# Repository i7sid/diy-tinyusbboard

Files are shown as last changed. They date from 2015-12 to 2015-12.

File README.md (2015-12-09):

# diy-tinyusbboard
Das DIY tinyUSBboard ist abgeleitet vom [tinyusbboard](https://github.com/tinyusbboard) und wurde für die Vorlesung ["DIY: Personal Fabrication"](http://www7.cs.fau.de/de/teaching/diy-2015w/) als Löttutorial entwickelt.

## In der Arduino IDE
Ab der Arduino IDE 1.6.4 kann man dieses Board mit der [Boards Manager URL](https://github.com/i7sid/diy-tinyusbboard/raw/master/Arduino/package_diy-tinyusbboard_index.json) hinzufügen.

Board Manager Link: `https://github.com/i7sid/diy-tinyusbboard/raw/master/Arduino/package_diy-tinyusbboard_index.json`

Zum Ätzen, Löten und ersten Programmieren besteht eine [Anleitung](https://github.com/i7sid/diy-tinyusbboard/raw/master/anleitung/anleitung.pdf).
### Arduino PIN-Belegung
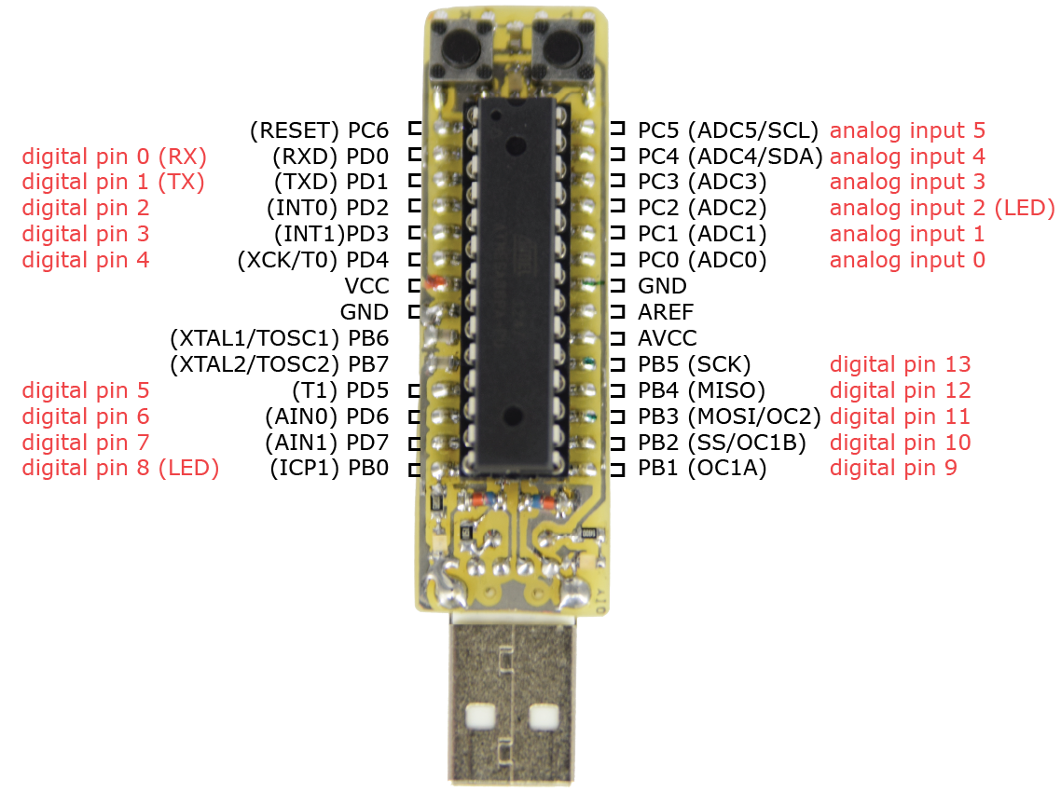
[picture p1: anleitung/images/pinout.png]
DIY tinyUSBboard Arduino PIN names


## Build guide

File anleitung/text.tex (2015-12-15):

\title{DIY tinyUSBboard}
\subtitle{Lötanleitung}
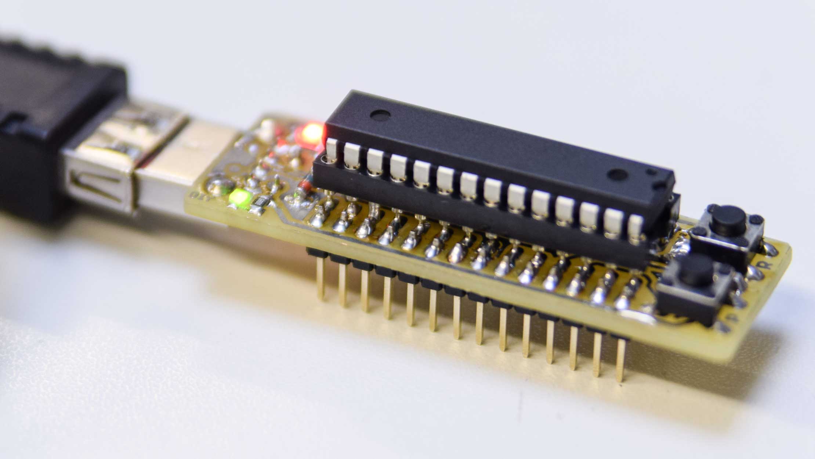
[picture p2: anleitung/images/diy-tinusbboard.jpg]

\section{Ätzen}
Zuerst muss das Layout auf die Platine geätzt werden.
Das Dokument spiegeln und mit möglichst hoher Tonerdichte ausgedrucken. Wenn nötig Photoplatine auf passende Größe zurecht sägen und Grate mit einer kleinen Feile entfernen. 
\paragraph*{Belichten} Die blaue Schutzfolie entfernen und auf dem gedruckten Layout im Belichter platzieren. Dabei muss die bedruckte Seite auf der beschichteten Seite der Platine aufliegen. Belichter schließen und mit empfohlene Belichtungszeit für den Belichter belichten. 
\paragraph*{Entwickeln} Mit aufgesetzter Schutzbrille die Platine, mit der beschichteten Seite nach oben, in die dafür vorgesehene Schale legen und mit etwas NaOH-Lösung begießen.
20-30 Sekunden schwenken bis keine braune Färbung mehr in die Lösung übergeht.
Platine mit einer Plastikpinzette aus der Lösung entnehmen und unter fliesendem Wasser abspülen.
\paragraph*{Ätzen} Warten bis das Ätzbad 40$^\circ$C erreicht hat. Ätzgerät ausschalten mit aufgesetzer Schutzbrille den Platinenhalter entnehmen, die Platine in den Halter einlegen. Halter in das Ätzbad stellen und Gerät wieder einschalten.
Ätzvorgang regelmäßig beobachten. Sobald alle gewünschten Stellen frei von Kupfer sind, Schutzbrille aufsetzen, Atzgerät ausschalten, Platinenhalter mit Platine entnehmen und mit Wasser abspülen.

\paragraph*{Entschichten} Platine erneut (ohne Papier ca. 2 Minuten) belichten und in die NaOH-Lösung geben. Schwenken, bis sich keine braune Farbe mehr löst.
Schale ins Waschbecken leeren und zusammen mit der Platine abspülen.
Platine im Verzinnungsbad verzinnen und erneut unter fließendem Wasser abwaschen.
\section{Bohren}
Beim Präzisionssockel kann man sich Zeit und abgebrochene Bohrer sparen, indem man nur die vier Ecken bohrt
\img{bohren.pdf}{Durchmesser der zu Bohrenden Löcher}
\section{Bestücken}
\subsection{SMT}
Die SMD Komponenten werden zuerst bestückt.
Dabei erhitzt man erst eines der Pads mit dem Lötkolben und bringt etwas Lötzinn auf. Dann wird das Bauteil mit einer Pinzette in die richtige Position gebracht. Das verzinnte Pad wird erneut erhitzt. Dann wird der andere Kontakt des Bauteils verlötet.
\paragraph*{Z-Dioden} Die Z-Dioden müssen richtig orientiert verlötet werden. Der blaue Ring markiert die Kathode der Diode. 

\img{z-dioden.pdf}{Orientierung und Position der Z-Dioden (blau)}

\paragraph*{Widerstände} Die Bauteilwerte sind auf den Widerständen aufgedruckt.
Dabei sind bei einer dreistelligen Aufschrift die ersten beiden Ziffern mit der Zehnerpotenz der dritten Ziffer zu multiplizieren. Beispiel $103 = 10 \cdot 10^3 = 10\,\mathrm{k}\Omega$\\
Bei vierstelliger Aufschrift werden die ersten drei Ziffern mit der Zehnerpotenz der letzten Ziffer multipliziert. Beispiel $6800 = 680 * 10^0 = 680\,\Omega$\\
Wird keine Zehnerpotenz angegeben wird der Buchstabe R an der Stelle des Kommas eingefügt. Beispiel $68\mathrm{R}0 = 68,0\,\Omega$
\img{widerstaende.pdf}{Position und Werte der Widerstände}

\paragraph*{Kondensatoren}
Die Kondensatoren lassen sich duch ihre Verpackung unterscheiden. Der einzige in Kunststoffhülle hat die Kapazität $1\,\mu \mathrm{F}$. Der zweier Abschnitt hat den Wert $18\,\mathrm{pF}$ und der übrige den Wert $100\, \mathrm{nF}$
\img{kondensatoren.pdf}{Position und Werte der Kondensatoren}
\paragraph*{LEDs}
Auf dem tinyUSBboard kommen eine grüne und zwei rote LEDs zum Einsatz.
\img{led-farbe.pdf}{Farben der LEDs}
\newpage
Die Kathode einer LED ist rückseitig, wie auf dem Schaltplan, mit einem Quadrat markiert.
\img{led-orientierung.pdf}{Markierung der Kathode im Bestückungsdruck und auf der \textbf{Rückseite} der LED}

\subsection{THT}
Nachdem alle SMD Komponenten verlötet sind werden die beiden Taster auf der Kupferseite verbaut.
Danach Oszillator, PTC-Widerstand und USB-Buchse; diese drei Komponenten werden von der Rückseite der Platine bestückt und auf der Kupferseite verlötet.
\img{tht.pdf}{Position THT Komponenten}

Erst wenn alle andere Komponenten mit Ausnahme der Stiftleisten verlötet sind wird der Sockel eingesetzt. Wenn nur die Löcher in den 4 Ecken gebohrt wurden müssen vor dem Löten die übrigen Pins gleichmäßig gekürzt werden. Der Sockel besitzt auf einer der Stirnseiten eine Kerbe, diese dient zur späteren Orientierung des ATmega88-PA und sollte zu den Tastern zeigen.
Nachdem der Sockel verbaut ist werden zuletzt die Stiftleisten von der Unterseite bestückt und auf der Kupferseite verlötet.\\
Jetzt kann der ATmega88PA in das Board eingesetzt werden. In einer Ecke ist ein Punkt für Pin 1 (Reset) eingeprägt, dieser muss zu den Tastern zeigen.

\section{tinyUSBboard in Arduino IDE}
Um das DIY tinyUSBboard in der Arduino IDE verwenden zu können ist eine aktuelle Arduino IDE vorausgesetzt. In der Arduino IDE die Einstellungen öffnen \enquote{File $\rightarrow$ Preferences} und in das Feld \enquote{Additional Boards Manager URLs} die URL \url{https://github.com/i7sid/diy-tinyusbboard/raw/master/Arduino/package_diy-tinyusbboard_index.json} kopieren. Unter \enquote{Tools $\rightarrow$ Board $\rightarrow$ Boards Manager} den Boards Manager aufrufen, den Eintrag diy-tinyusbboard auswählen und \enquote{Install} klicken. Jetzt kann das diy-tinyusbboard ausgewählt werden \enquote{Tools $\rightarrow$ Board $\rightarrow$ DIY tinyUSBboard (USBaspLoader ATmega88p at 16MHz)}.\footnote{Für Windows muss zusätzlich ein Treiber für USBasp installiert werden. \url{http://www.fischl.de/usbasp/}}
\image{boards-manager.png}{tinyUSBboard im Boards Manager}
\subsection{Bootloader flashen}
Zum flashen des Bootloaders muss das tinyUSBboard an einen AVR ISP\footnote{z.B. Atmel AVRISP mkII oder USBasp} angeschlossen werden. Je nach ISP muss das Board noch z.B. über die USB-Buchse mit Spannung versorgt werden.
\img{prog.pdf}{ISP an das tinyUSBboard anschließen}

Wenn in der Arduino IDE das richtige Board ausgewählt ist muss noch der verwendete ISP eingestellt werden \enquote{Tools $\rightarrow$ Programmer}. Jetzt kann mit \enquote{Tools $\rightarrow$ Burn Bootloader} der Bootloader auf das DIY tinyUSBboard geflasht werden.

\subsection{Sketch auf das Board flashen}
Um das tinyUSBboard in den Programmiermodus zu bringen muss der \textbf{P}-Taster gedrückt werden, während der \textbf{R}-Taster losgelassen wird. Das tinyUSBboard meldet sich jetzt als USBasp ISP am Computer an und lässt sich in der Arduino IDE mit \enquote{Sketch $\rightarrow$ Upload} programmieren. Wenn die Arduino IDE \enquote{Done uploading.} angezeigt wird, kann der Programmablauf durch Drücken einer der Tasten gestartet werden. 
\image{pinout.pdf}{Arduino PIN-Namen}

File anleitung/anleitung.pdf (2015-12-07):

## DIY tinyUSBboard


## 1 Atzen ¨

Zuerst muss das Layout auf die Platine geätzt werden. Das Dokument spiegeln und mit möglichst hoher Tonerdichte ausgedrucken. Wenn nötig Photoplatine auf passende Größe zurecht sägen und Grate mit einer kleinen Feile entfernen.

Belichten Die blaue Schutzfolie entfernen und auf dem gedruckten Layout im Belichter platzieren. Dabei muss die bedruckte Seite auf der beschichteten Seite der Platine aufliegen. Belichter schließen und mit empfohlene Belichtungszeit fur den Belichter belichten. ¨

Entwickeln Mit aufgesetzter Schutzbrille die Platine, mit der beschichteten Seite nach oben, in die dafur ¨ vorgesehene Schale legen und mit etwas NaOH-Lösung begießen. 20-30 Sekunden schwenken bis keine
braune Färbung mehr in die Lösung ubergeht. Platine mit einer Plastikpinzette aus der L ¨ | ösung entnehmen
und unter fliesendem Wasser abspulen. ¨
Atzen ¨ | Warten bis das Atzbad 40 ¨ | ◦C erreicht hat. Atzger ¨ | ät ausschalten mit aufgesetzer Schutzbrille den
Platinenhalter entnehmen, die Platine in den Halter einlegen. Halter in das Atzbad stellen und Ger ¨ | ät
wieder einschalten. Atzvorgang regelm ¨ | äßig beobachten. Sobald alle gewunschten Stellen frei von Kupfer ¨

sind, Schutzbrille aufsetzen, Atzgerät ausschalten, Platinenhalter mit Platine entnehmen und mit Wasser abspulen. ¨

kontakt@fablab.fau.de | 7. Dezember 2015

Entschichten Platine erneut (ohne Papier ca. 2 Minuten) belichten und in die NaOH-Lösung geben.

Schwenken, bis sich keine braune Farbe mehr löst. Schale ins Waschbecken leeren und zusammen mit der Platine abspulen. Platine im Verzinnungsbad verzinnen und erneut unter fließendem Wasser abwaschen. ¨

## 2 Bohren

Beim Präzisionssockel kann man sich Zeit und abgebrochene Bohrer sparen, indem man nur die vier Ecken
0.8 mm
0.9 mm

1.2 mm

1.0 mm

2.2 mm

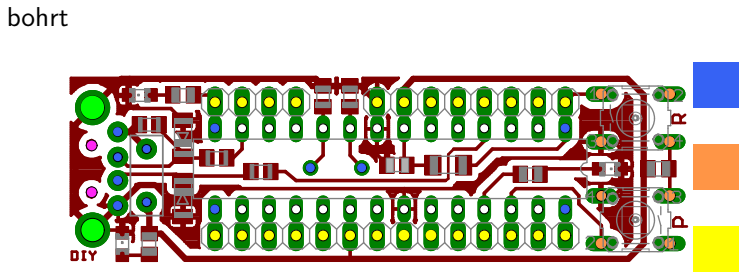
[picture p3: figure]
bohrt

Abbildung 1: Durchmesser der zu Bohrenden Löcher

## 3 Bestücken

### 3.1 SMT

Die SMD Komponenten werden zuerst bestuckt. Dabei erhitzt man erst eines der Pads mit dem L ¨ | ötkolben
und bringt etwas Lötzinn auf. Dann wird das Bauteil mit einer Pinzette in die richtige Position gebracht. Das verzinnte Pad wird erneut erhitzt. Dann wird der andere Kontakt des Bauteils verlötet.
Z-Dioden Die Z-Dioden mussen richtig orientiert verl ¨ | ötet werden. Der blaue Ring markiert die Kathode
der Diode.

Abbildung 2: Orientierung und Position der Z-Dioden (blau)

Widerstände Die Bauteilwerte sind auf den Widerständen aufgedruckt. Dabei sind bei einer dreistelligen Aufschrift die ersten beiden Ziffern mit der Zehnerpotenz der dritten Ziffer zu multiplizieren. Beispiel 103 = 10 · 10³ = 10 kΩ

Bei vierstelliger Aufschrift werden die ersten drei Ziffern mit der Zehnerpotenz der letzten Ziffer multipliziert.

Beispiel 6800 = 680 ∗ 10⁰ = 680 Ω

Wird keine Zehnerpotenz angegeben wird der Buchstabe R an der Stelle des Kommas eingefugt. Beispiel ¨

10k | (103)
68 | (68R0)

1.5k (1501)

680 (6800)

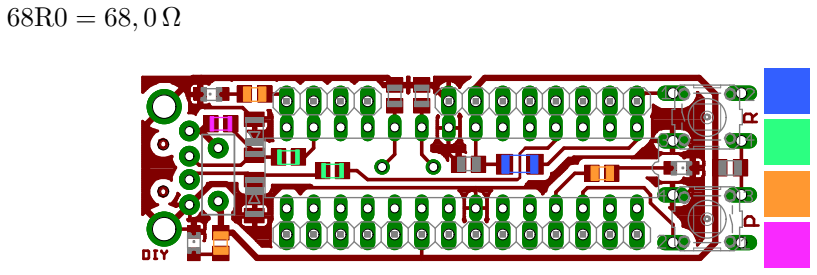
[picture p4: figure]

Abbildung 3: Position und Werte der Widerstände

Kondensatoren Die Kondensatoren lassen sich duch ihre Verpackung unterscheiden. Der einzige in
Kunststoffhulle hat die Kapazit ¨ | ät 1 µF. Der zweier Abschnitt hat den Wert 18 pF und der ubrige den Wert ¨
100 nF
1µF
100 nF
18pF

Abbildung 4: Position und Werte der Kondensatoren

LEDs Auf dem tinyUSBboard kommen eine grune und zwei rote LEDs zum Einsatz. ¨

Abbildung 5: Farben der LEDs

Die Kathode einer LED ist ruckseitig, wie auf dem Schaltplan, mit einem Quadrat markiert. ¨

# Kathode

# Anode

Abbildung 6: Markierung der Kathode

### 3.2 THT

Nachdem alle SMD Komponenten verlötet sind werden die beiden Taster auf der Kupferseite verbaut. Danach Oszillator, PTC-Widerstand und USB-Buchse; diese drei Komponenten werden von der Ruckseite ¨
der Platine bestuckt und auf der Kupferseite verl ¨ | ötet.

# OSC Taster

# PTC

# USB

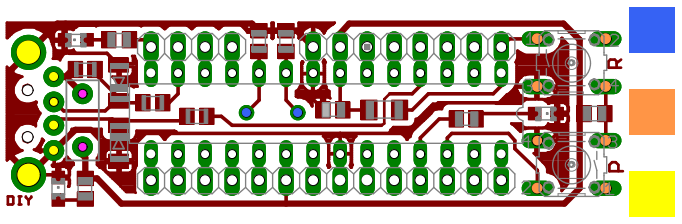
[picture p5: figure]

Abbildung 7: Position THT Komponenten

Erst wenn alle andere Komponenten mit Ausnahme der Stiftleisten verlötet sind wird der Sockel eingesetzt.
Wenn nur die Löcher in den 4 Ecken gebohrt wurden mussen vor dem L ¨ | öten die ubrigen Pins gleichm ¨ | äßig
gekurzt werden. Nachdem der Sockel verbaut ist werden zuletzt die Stiftleisten von der Unterseite best ¨ | | uckt ¨
und auf der Kupferseite verlötet.

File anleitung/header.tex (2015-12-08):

\newcommand{\basedir}{fablab-document}
\documentclass{\basedir/fablab-document}

% \usepackage{fancybox} %ovale Boxen für Knöpfe - nicht mehr benötigt
\usepackage{amssymb} % Symbole für Knöpfe
\usepackage{subfigure,caption}
\usepackage{eurosym}
\usepackage{tabularx} % Tabellen mit bestimmtem Breitenverhältnis der Spalten
\usepackage{wrapfig} % Textumlauf um Bilder

\renewcommand{\texteuro}{\euro}

\definecolor{dunkelgruen}{rgb}{0,0.4,0}

\newcommand{\img}[2]{
	\begin{figure}[ht]
	\centering
	
	\caption{#2}
	\end{figure}}
	
\newcommand{\image}[2]{
	\begin{figure}[ht]
	\centering
	
	\caption{#2}
	\end{figure}}
	
\newcommand\circlearound[1]{%
  \tikz[baseline]\node[draw,shape=circle,anchor=base] {#1} ;}
	
\newcounter{ueberpunkte}
\setcounter{ueberpunkte}{1}
\renewcommand{\labelenumi}{\circlearound{\theueberpunkte}\stepcounter{ueberpunkte}}

\linespread{1.2}

\title{DIY tinyUSBboard}

\begin{document}

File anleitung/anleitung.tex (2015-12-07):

\input{header}
\input{text}
\input{footer}

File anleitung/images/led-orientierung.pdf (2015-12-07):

Kathode

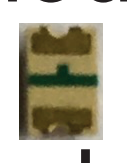
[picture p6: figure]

Anode

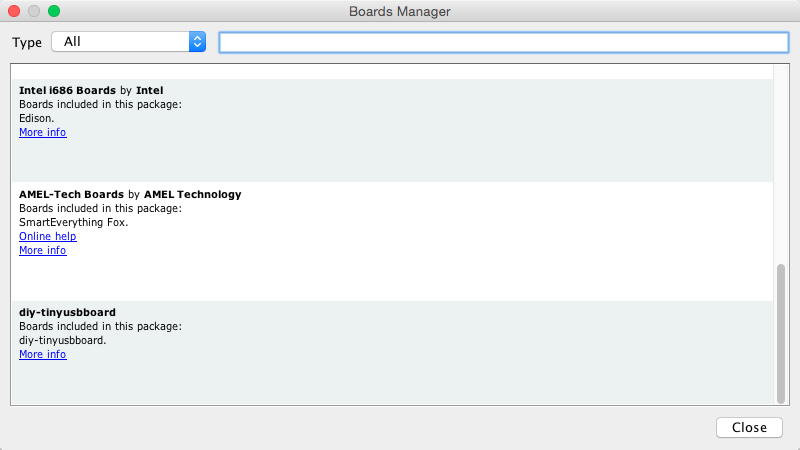
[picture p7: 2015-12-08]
anleitung/images/boards-manager.png

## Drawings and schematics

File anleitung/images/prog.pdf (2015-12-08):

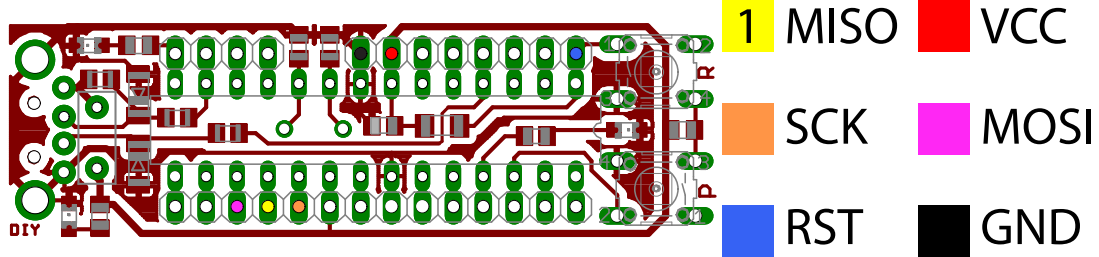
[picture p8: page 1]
RST; SCK; MOSI; MISO; GND; VCC

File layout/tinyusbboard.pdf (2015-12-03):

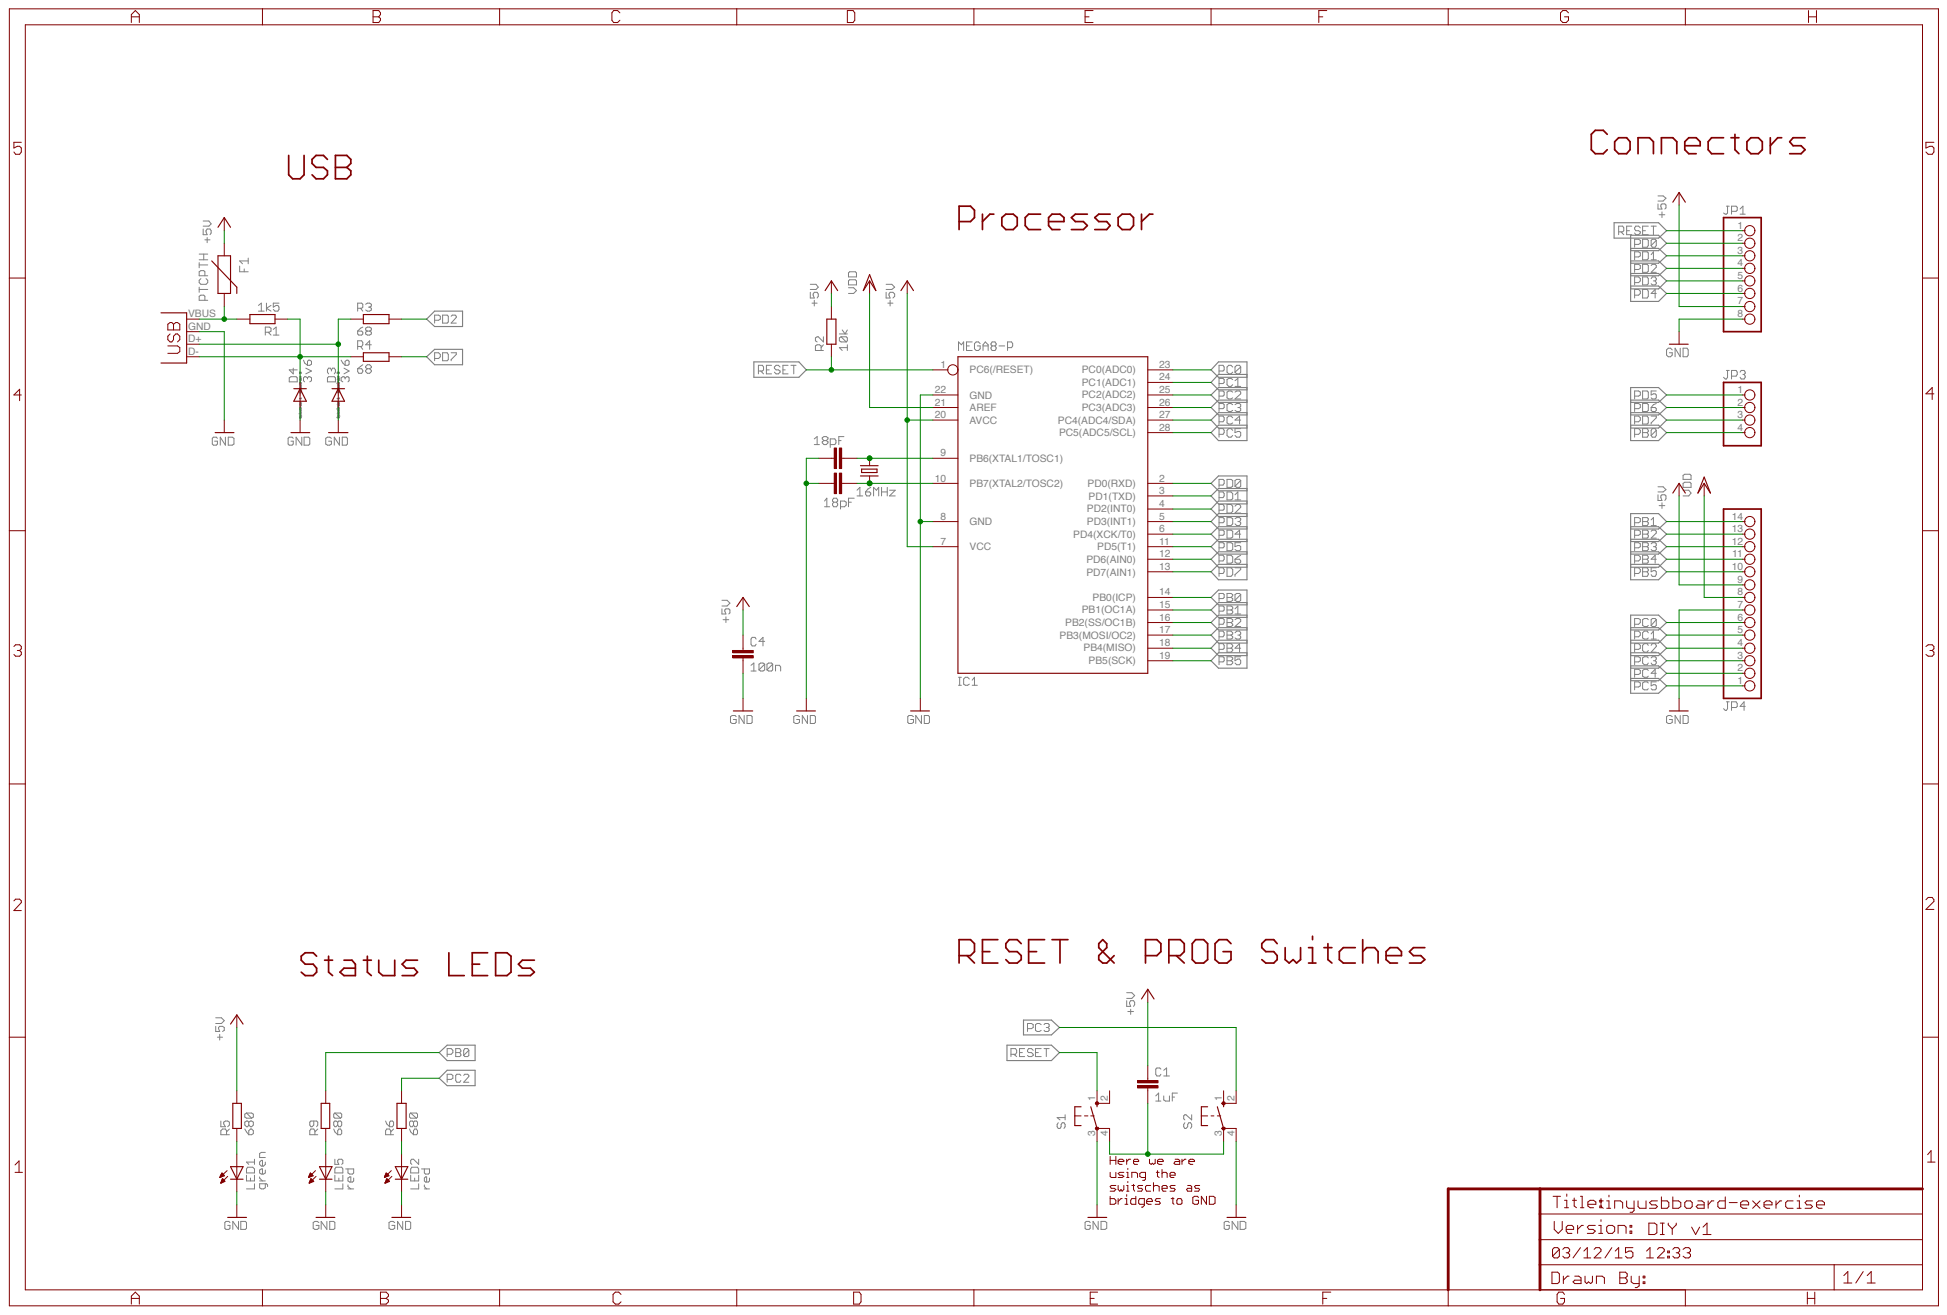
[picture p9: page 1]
PB5(SCK); PB6(XTAL1/TOSC1); GND; VCC; GND 22 AREF 21; PB4(MISO); 18 PB3(MOSI/OC2); 15 PB0(ICP); PD7(AIN1); 13 PD6(AIN0); 11 PD4(XCK/T0); 6 PD3(INT1); 5 PD2(INT0); 4 PD1(TXD); 3 PD0(RXD); PC5(ADC5/SCL); 28 PC4(ADC4/SDA); 27 PC3(ADC3); 26 PC2(ADC2); 25 PC1(ADC1); 24 PC0(ADC0); 23 PC6(/RESET); VBUS

AVCC 20

PB7(XTAL2/TOSC2) 10

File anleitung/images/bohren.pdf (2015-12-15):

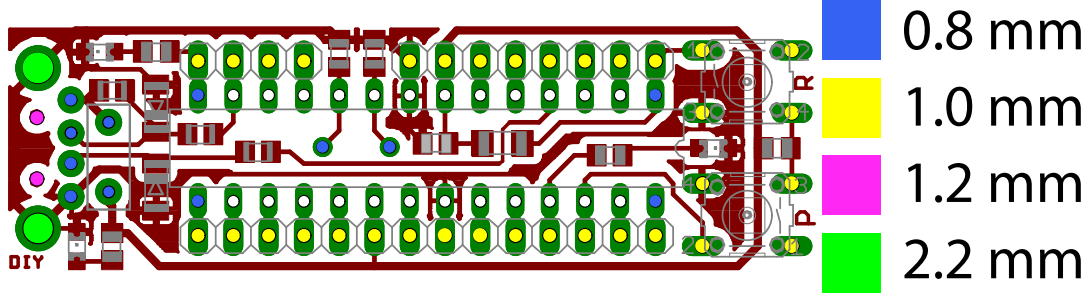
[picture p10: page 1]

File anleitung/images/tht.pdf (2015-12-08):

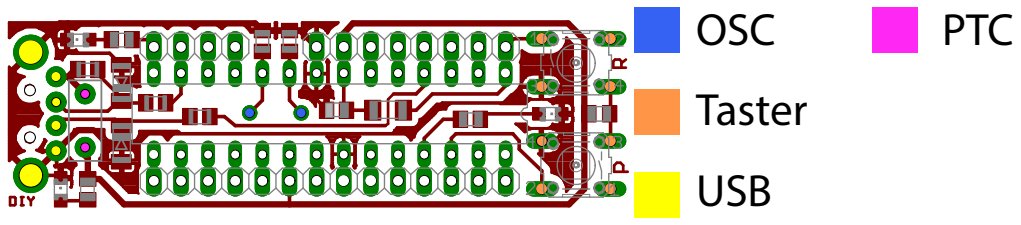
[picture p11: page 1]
OSC Taster; PTC; USB

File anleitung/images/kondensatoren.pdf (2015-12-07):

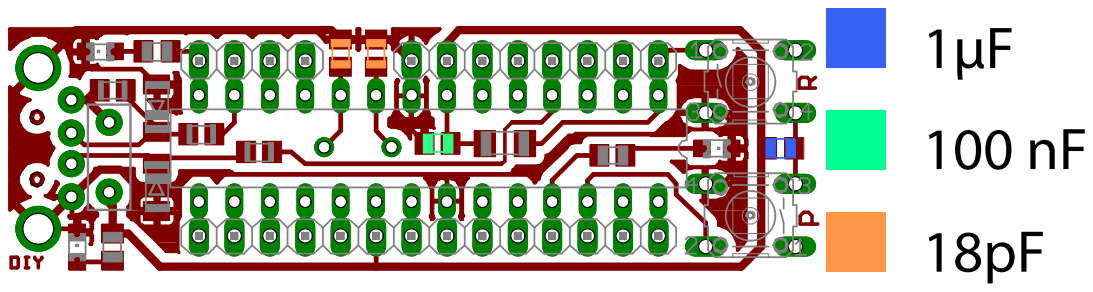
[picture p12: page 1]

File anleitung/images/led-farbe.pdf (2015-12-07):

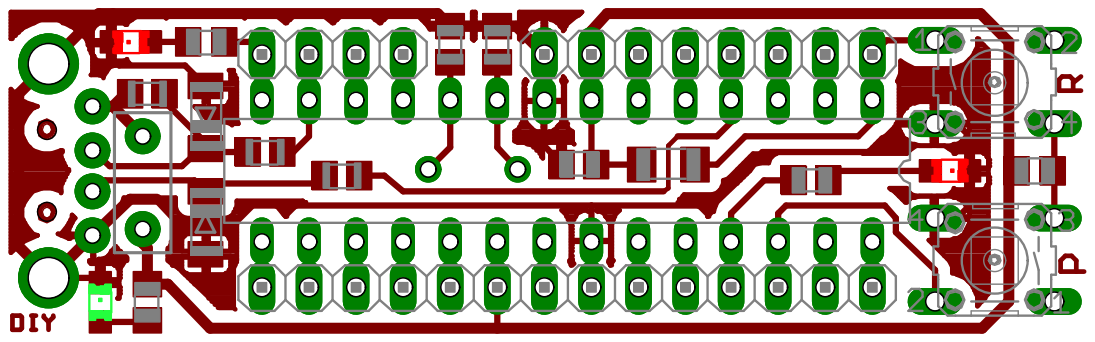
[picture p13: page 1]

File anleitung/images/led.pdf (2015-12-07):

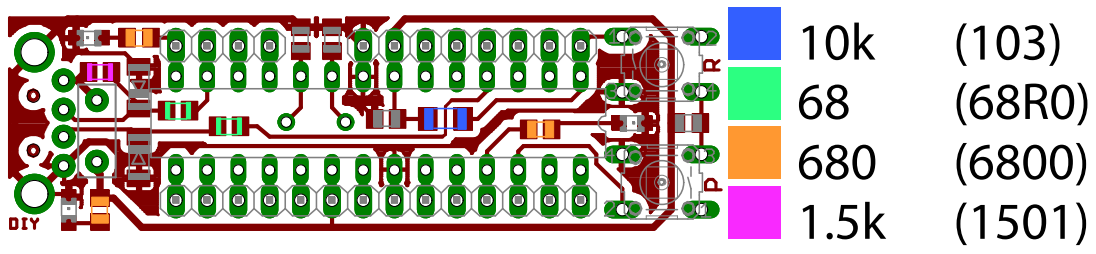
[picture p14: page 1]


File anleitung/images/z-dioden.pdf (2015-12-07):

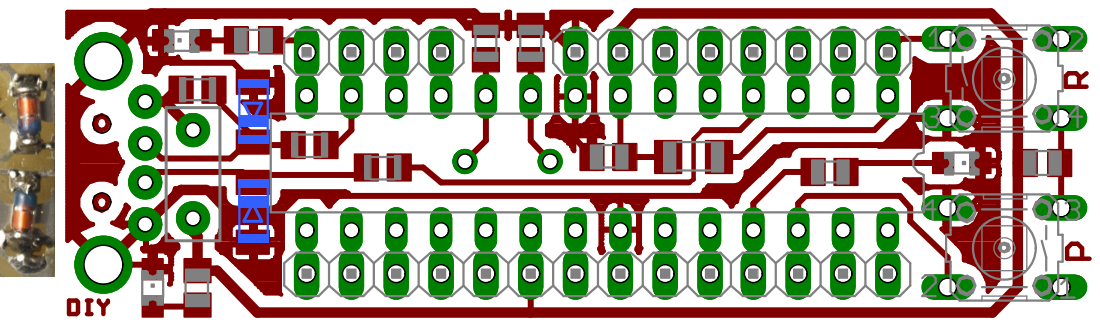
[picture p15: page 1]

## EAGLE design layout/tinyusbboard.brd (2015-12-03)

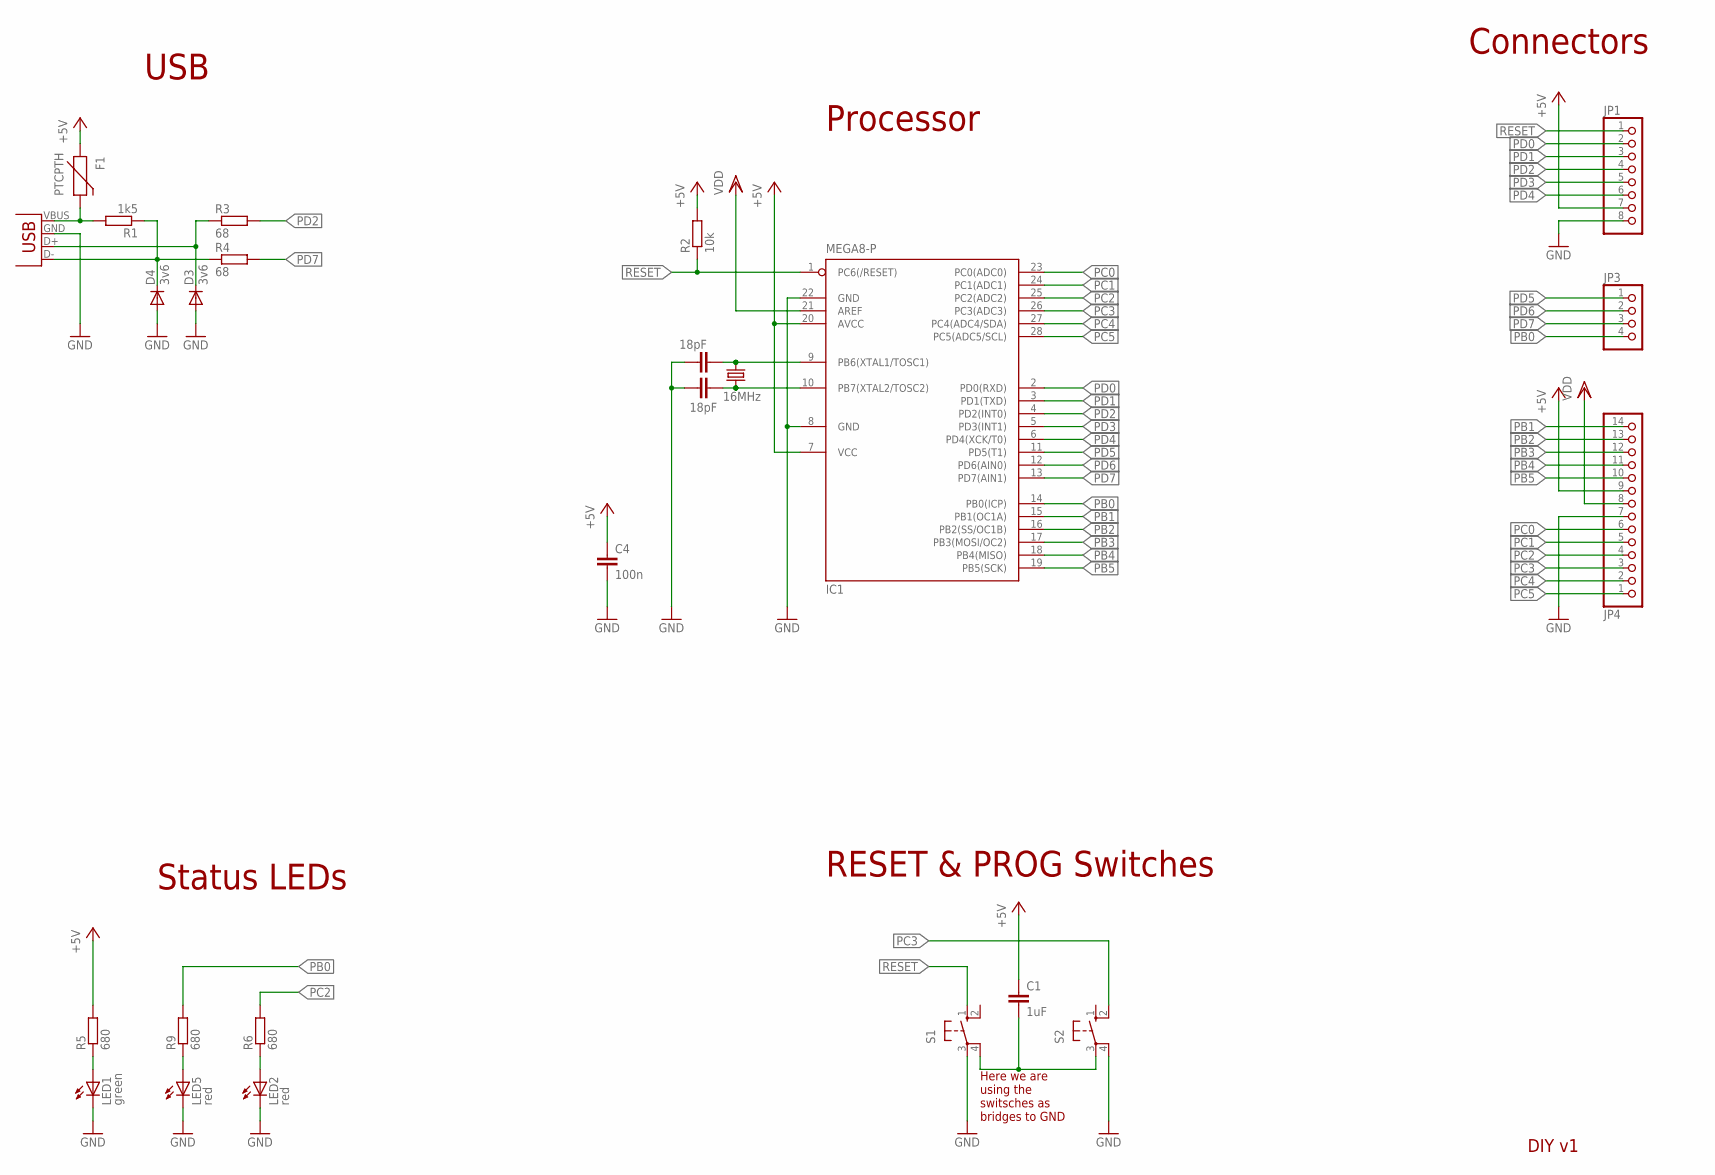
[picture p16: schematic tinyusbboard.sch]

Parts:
C1: 1uF; C0805
C2, C3: 18pF; C0805K
C4: 100n; C0805
D3, D4: 3v6; MINIMELF
F1: PTCPTH; PTC
IC1: MEGA8-P; DIL28-3
JP1: PINHD-1X8; 1X08
JP3: PINHD-1X4; 1X04
JP4: PINHD-1X14; 1X14
JP5: USB-A-H
LED1: green; CHIPLED_0805
LED2, LED5: red; CHIPLED_0805
Q1: 16MHz; HC49/S
R1: 1k5; M0805
R2: 10k; R1206
R3, R4: 68; M0805
R5, R6, R9: 680; R0805
S1, S2: 10-XX; B3F-10XX

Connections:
+5V: C1.1, C4.1, F1.P$1 (1), IC1.7 (VCC), IC1.20 (AVCC), JP1.7, JP4.9, R2.2, R5.2
D+: D3.C, JP5.D+ (D-), R3.1
D-: D4.C, JP5.D- (D+), R1.1, R4.1
GND: C2.2, C3.2, C4.2, D3.A, D4.A, IC1.8 (GND), IC1.22 (GND), JP1.8, JP4.7, JP5.GND (VBUS), LED1.C, LED2.C, LED5.C, S1.3, S2.4 (P1)
unnamed: F1.P$2 (2), JP5.VBUS (GND), R1.2
unnamed: LED1.A, R5.1
unnamed: C3.1, IC1.9 (PB6(XTAL1/TOSC1)), Q1.1
unnamed: C2.1, IC1.10 (PB7(XTAL2/TOSC2)), Q1.2
unnamed: LED5.A, R9.1
unnamed: LED2.A, R6.1
unnamed: C1.2, S1.4 (P1), S2.3
PB0: IC1.14 (PB0(ICP)), JP3.4, R9.2
PB1: IC1.15 (PB1(OC1A)), JP4.14
PB2: IC1.16 (PB2(SS/OC1B)), JP4.13
PB3: IC1.17 (PB3(MOSI/OC2)), JP4.12
PB4: IC1.18 (PB4(MISO)), JP4.11
PB5: IC1.19 (PB5(SCK)), JP4.10
PC0: IC1.23 (PC0(ADC0)), JP4.6
PC1: IC1.24 (PC1(ADC1)), JP4.5
PC2: IC1.25 (PC2(ADC2)), JP4.4, R6.2
PC3: IC1.26 (PC3(ADC3)), JP4.3, S2.2 (S1)
PC4: IC1.27 (PC4(ADC4/SDA)), JP4.2
PC5: IC1.28 (PC5(ADC5/SCL)), JP4.1
PD0: IC1.2 (PD0(RXD)), JP1.2
PD1: IC1.3 (PD1(TXD)), JP1.3
PD2: IC1.4 (PD2(INT0)), JP1.4, R3.2
PD3: IC1.5 (PD3(INT1)), JP1.5
PD4: IC1.6 (PD4(XCK/T0)), JP1.6
PD5: IC1.11 (PD5(T1)), JP3.1
PD6: IC1.12 (PD6(AIN0)), JP3.2
PD7: IC1.13 (PD7(AIN1)), JP3.3, R4.2
RESET: IC1.1 (PC6(/RESET)), JP1.1, R2.1, S1.1 (S)
VDD: IC1.21 (AREF), JP4.8

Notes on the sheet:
Status LEDs
Connectors
RESET & PROG Switches
DIY v1
Processor
USB
Here we are using the switsches as bridges to GND

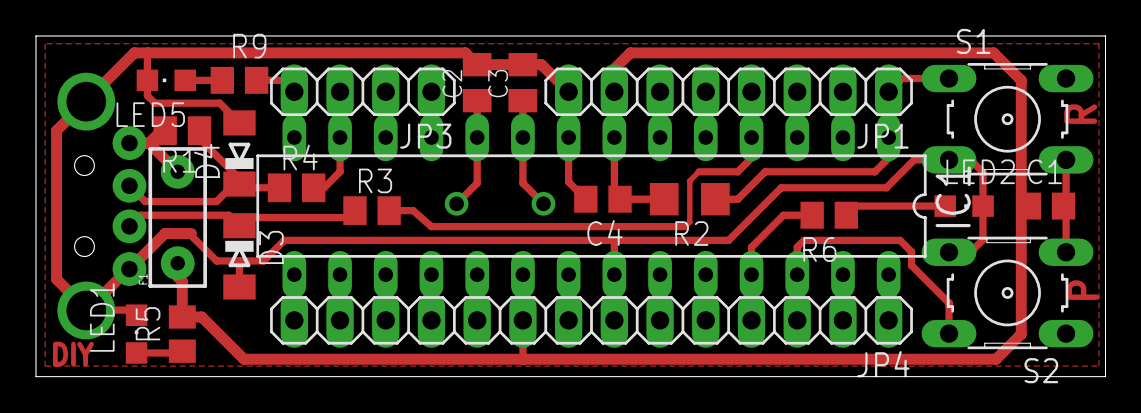
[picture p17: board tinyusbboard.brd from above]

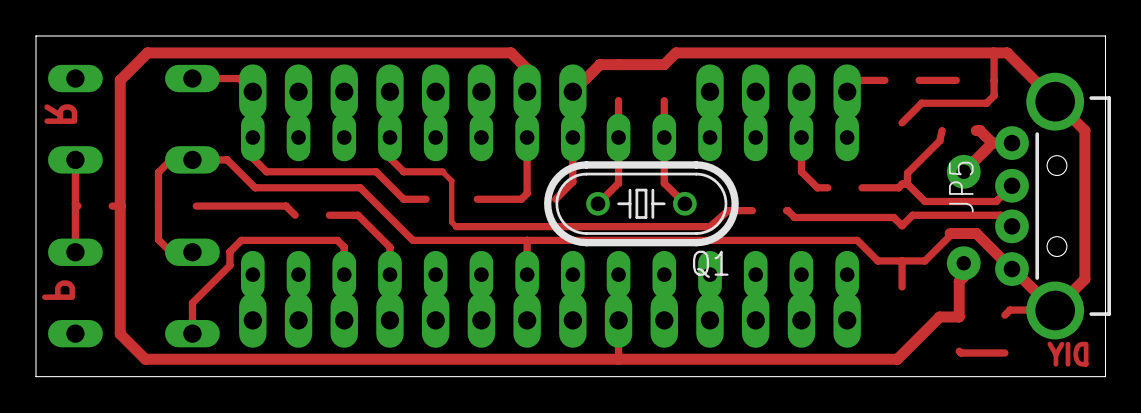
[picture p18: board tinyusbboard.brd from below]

Board: 2 copper layers, 59.4 x 18.9 mm, 25 parts (2 on the bottom side), 33 nets.

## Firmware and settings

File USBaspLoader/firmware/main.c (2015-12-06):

/* Name: main.c
 * Project: USBaspLoader
 * Author: Christian Starkjohann
 * Author: Stephan Baerwolf
 * Creation Date: 2007-12-08
 * Modification Date: 2013-03-31
 * Tabsize: 4
 * Copyright: (c) 2007 by OBJECTIVE DEVELOPMENT Software GmbH
 * License: GNU GPL v2 (see License.txt)
 */

#include "spminterface.h"  /* must be included as first! */

#include "../misc/iofixes.h"

#include <avr/interrupt.h>
#include <avr/pgmspace.h>
#include <avr/wdt.h>
#include <avr/boot.h>
#include <avr/eeprom.h>
#include <util/delay.h>


#if 0
/*
 * 29.09.2012 /  30.09.2012
 * 
 * Since cpufunc.h is not needed in this context and
 * since it is not available in all toolchains, this include
 * becomes deactivated by github issue-report.
 * (In case of trouble it remains in sourcecode for reactivation.)
 * 
 * The autor would like to thank Lena-M for reporting this
 * issue (https://github.com/baerwolf/USBaspLoader/issues/1).
 */
#include <avr/cpufunc.h>
#endif

#include <avr/boot.h>

#include <string.h>



#include "bootloaderconfig.h"

#include "usbdrv/usbdrv.c"
static usbMsgLen_t usbFunctionDescriptor(struct usbRequest *rq) {
  return 0;
}

#ifndef BOOTLOADER_ADDRESS
  #error need to know the bootloaders flash address!
#endif
#define BOOTLOADER_PAGEADDR	(BOOTLOADER_ADDRESS - (BOOTLOADER_ADDRESS % SPM_PAGESIZE))

/* ------------------------------------------------------------------------ */

/* Request constants used by USBasp */
#define USBASP_FUNC_CONNECT         1
#define USBASP_FUNC_DISCONNECT      2
#define USBASP_FUNC_TRANSMIT        3
#define USBASP_FUNC_READFLASH       4
#define USBASP_FUNC_ENABLEPROG      5
#define USBASP_FUNC_WRITEFLASH      6
#define USBASP_FUNC_READEEPROM      7
#define USBASP_FUNC_WRITEEEPROM     8
#define USBASP_FUNC_SETLONGADDRESS  9

// additional USBasp Commands
#define USBASP_FUNC_SETISPSCK	     10
#define USBASP_FUNC_TPI_CONNECT      11
#define USBASP_FUNC_TPI_DISCONNECT   12
#define USBASP_FUNC_TPI_RAWREAD      13
#define USBASP_FUNC_TPI_RAWWRITE     14
#define USBASP_FUNC_TPI_READBLOCK    15
#define USBASP_FUNC_TPI_WRITEBLOCK   16
#define USBASP_FUNC_GETCAPABILITIES 127
/* ------------------------------------------------------------------------ */

#ifndef ulong
#   define ulong    unsigned long
#endif
#ifndef uint
#   define uint     unsigned int
#endif


/* allow compatibility with avrusbboot's bootloaderconfig.h: */
#ifdef BOOTLOADER_INIT
#   define bootLoaderInit()         BOOTLOADER_INIT
#   define bootLoaderExit()
#endif
#ifdef BOOTLOADER_CONDITION
#   define bootLoaderCondition()    BOOTLOADER_CONDITION
#endif

/* device compatibility: */
#ifndef GICR    /* ATMega*8 don't have GICR, use MCUCR instead */
#   define GICR     MCUCR
#endif

/* ------------------------------------------------------------------------ */

#if (FLASHEND) > 0xffff /* we need long addressing */
#   define CURRENT_ADDRESS  currentAddress.l
#   define addr_t           ulong
#else
#   define CURRENT_ADDRESS  currentAddress.w[0]
#   define addr_t           uint
#endif

typedef union longConverter{
    addr_t  l;
    uint    w[sizeof(addr_t)/2];
    uchar   b[sizeof(addr_t)];
}longConverter_t;


#define __IMPLEMENT_PRESERVE_WATCHDOG	((PRESERVE_WATCHDOG) && (!(USE_EXCESSIVE_ASSEMBLER)) && ((NEED_WATCHDOG) || (defined(__MCUCSR_COMPATMODE))))
#if (__IMPLEMENT_PRESERVE_WATCHDOG)
static uint8_t __original_WDTCR;
#endif

#if (BOOTLOADER_CAN_EXIT)
#	if (BOOTLOADER_LOOPCYCLES_TIMEOUT)
#		if (BOOTLOADER_LOOPCYCLES_TIMEOUT < 256)
#			if ((HAVE_UNPRECISEWAIT))
	 register uint8_t timeout_remaining __asm__("r2");
#			else
static volatile uint8_t timeout_remaining;
#			endif
#		else
static volatile uint16_t timeout_remaining;
#		endif
#	endif

#	define stayinloader_initialValue 0xfe
#	if ((HAVE_UNPRECISEWAIT))
/* here we have to assume we need to optimize for every byte */
	 register uint8_t stayinloader __asm__("r17");
#	else
static volatile uint8_t stayinloader;
#	endif
#endif

static longConverter_t  	currentAddress; /* in bytes */
static uchar            	bytesRemaining;
static uchar            	isLastPage;
#if HAVE_EEPROM_PAGED_ACCESS
static uchar            	currentRequest;
#else
static const uchar      	currentRequest = 0;
#endif

static const uchar  signatureBytes[4] = {
#ifdef SIGNATURE_BYTES
    SIGNATURE_BYTES
#elif defined (__AVR_ATmega8535__)
    0x1e, 0x93, 0x08, 0
#elif defined (__AVR_ATmega8__) || defined (__AVR_ATmega8A__) || defined (__AVR_ATmega8HVA__)
    0x1e, 0x93, 0x07, 0
#elif defined (__AVR_ATmega16__)
    0x1e, 0x94, 0x03, 0
#elif defined (__AVR_ATmega32__)
    0x1e, 0x95, 0x02, 0
#elif defined (__AVR_ATmega48__) || defined (__AVR_ATmega48A__) || defined (__AVR_ATmega48P__)
    #error ATmega48 does not support bootloaders!
    0x1e, 0x92, 0x05, 0
#elif defined (__AVR_ATmega48PA__)
    #error ATmega48 does not support bootloaders!
    0x1e, 0x92, 0x0A, 0
#elif defined (__AVR_ATmega88__) || defined (__AVR_ATmega88A__) 
    0x1e, 0x93, 0x0a, 0
#elif defined (__AVR_ATmega88PA__) || defined (__AVR_ATmega88P__)
    0x1e, 0x93, 0x0F, 0
#elif defined (__AVR_ATmega162__)
    0x1e, 0x94, 0x04, 0
#elif defined (__AVR_ATmega164A__)
    0x1e, 0x94, 0x0f, 0
#elif defined (__AVR_ATmega164P__) || defined (__AVR_ATmega164PA__)
    0x1e, 0x94, 0x0a, 0
#elif defined (__AVR_ATmega168__) || defined (__AVR_ATmega168A__) || defined (__AVR_ATmega168P__)
    0x1e, 0x94, 0x06, 0
#elif defined (__AVR_ATmega168PA__)
    0x1e, 0x94, 0x0B, 0
#elif defined (__AVR_ATmega324A__)
    0x1e, 0x95, 0x15, 0
#elif defined (__AVR_ATmega324P__)
    0x1e, 0x95, 0x08, 0
#elif defined (__AVR_ATmega324PA__)
    0x1e, 0x95, 0x11, 0
#elif defined (__AVR_ATmega328__)
    0x1e, 0x95, 0x14, 0
#elif defined (__AVR_ATmega328P__)
    0x1e, 0x95, 0x0f, 0
#elif defined (__AVR_ATmega640__)
    0x1e, 0x96, 0x08, 0
#elif defined (__AVR_ATmega644__) || defined (__AVR_ATmega644A__)
    0x1e, 0x96, 0x09, 0
#elif defined (__AVR_ATmega644P__) || defined (__AVR_ATmega644PA__)
    0x1e, 0x96, 0x0a, 0
#elif defined (__AVR_ATmega128__)
    0x1e, 0x97, 0x02, 0
#elif defined (__AVR_ATmega1280__)
    0x1e, 0x97, 0x03, 0
#elif defined (__AVR_ATmega1281__)
    0x1e, 0x97, 0x04, 0
#elif defined (__AVR_ATmega1284__)
    0x1e, 0x97, 0x06, 0
#elif defined (__AVR_ATmega1284P__)
    0x1e, 0x97, 0x05, 0
#elif defined (__AVR_ATmega2560__)
    0x1e, 0x98, 0x01, 0
#elif defined (__AVR_ATmega2561__)
    0x1e, 0x98, 0x02, 0
#else
#   if (defined(SIGNATURE_0) && defined(SIGNATURE_1) && defined(SIGNATURE_2))
#     warning "Device signature is not known - using AVR Libc suggestion..."
    SIGNATURE_0, SIGNATURE_1, SIGNATURE_2, 0
#   else
#     error "Device signature is not known, please edit main.c!"
#   endif
#endif
};

/* ------------------------------------------------------------------------ */

#if (HAVE_BOOTLOADERENTRY_FROMSOFTWARE)
void __attribute__ ((section(".init3"),naked,used,no_instrument_function)) __BOOTLOADERENTRY_FROMSOFTWARE__bootup_investigate_RAMEND(void);
void __BOOTLOADERENTRY_FROMSOFTWARE__bootup_investigate_RAMEND(void) {
  asm volatile (
    "in		%[mcucsrval]	,	%[mcucsrio]\n\t"
    "ldi	r29		,	%[ramendhi]\n\t"
    "ldi	r28		,	%[ramendlo]\n\t"
#if (FLASHEND>131071)
    "ld		%[result]	,	Y+\n\t"
    "cpi	%[result]	,	%[bootaddrhi]\n\t"
    "brne	__BOOTLOADERENTRY_FROMSOFTWARE__bootup_investigate_RAMEND_mismatch%=\n\t"
#endif
    "ld		%[result]	,	Y+\n\t"
    "cpi	%[result]	,	%[bootaddrme]\n\t"
    "ld		%[result]	,	Y+\n\t"
    "breq	__BOOTLOADERENTRY_FROMSOFTWARE__bootup_investigate_RAMEND_done%=\n\t"

    "__BOOTLOADERENTRY_FROMSOFTWARE__bootup_investigate_RAMEND_mismatch%=:\n\t"
    "ldi	%[result]	,	0xff\n\t"

    "__BOOTLOADERENTRY_FROMSOFTWARE__bootup_investigate_RAMEND_done%=:\n\t"
    : [result]		"=a" (__BOOTLOADERENTRY_FROMSOFTWARE__bootup_RAMEND_doesmatch),
      [mcucsrval]	"=a" (__BOOTLOADERENTRY_FROMSOFTWARE__bootup_MCUCSR)
    : [mcucsrio]	"I"  (_SFR_IO_ADDR(MCUCSR)),
#if (FLASHEND>131071)
      [ramendhi]	"M" (((RAMEND - 2) >> 8) & 0xff),
      [ramendlo]	"M" (((RAMEND - 2) >> 0) & 0xff),
      [bootaddrhi]	"M" (((__BOOTLOADERENTRY_FROMSOFTWARE__EXPECTEDADDRESS) >>16) & 0xff),
#else
      [ramendhi]	"M" (((RAMEND - 1) >> 8) & 0xff),
      [ramendlo]	"M" (((RAMEND - 1) >> 0) & 0xff),
#endif
      [bootaddrme]	"M" (((__BOOTLOADERENTRY_FROMSOFTWARE__EXPECTEDADDRESS) >> 8) & 0xff)
    
  );
}
#endif

#if (USE_BOOTUP_CLEARRAM)
/*
* Under normal circumstances, RESET will not clear contents of RAM.
* As always, if you want it done - do it yourself...
*/
void __attribute__ ((section(".init3"),naked,used,no_instrument_function)) __func_clearram(void);
void __func_clearram(void) {
  extern size_t __bss_end;
  asm volatile (
    "__clearram:\n\t"
#if (!(HAVE_BOOTLOADERENTRY_FROMSOFTWARE))
    "ldi r29, %[ramendhi]\n\t"
    "ldi r28, %[ramendlo]\n\t"
#endif
    "__clearramloop%=:\n\t"
    "st -Y , __zero_reg__\n\t"
    "cp r28, %A[bssend]\n\t"
    "cpc r29, %B[bssend]\n\t"
    "brne __clearramloop%=\n\t"
    :
    : [ramendhi] "M" (((RAMEND+1)>>8) & 0xff),
      [ramendlo] "M" (((RAMEND+1)>>0) & 0xff),
      [bssend] "r" (&__bss_end)
    : "memory"
      );
}
#endif

#if (!USE_EXCESSIVE_ASSEMBLER) || (!(defined (__AVR_ATmega8__) || defined (__AVR_ATmega8A__) || defined (__AVR_ATmega8HVA__)))
static void (*nullVector)(void) __attribute__((__noreturn__));
#endif

#if (USE_EXCESSIVE_ASSEMBLER) && (defined (__AVR_ATmega8__) || defined (__AVR_ATmega8A__) || defined (__AVR_ATmega8HVA__))
static void __attribute__((naked,__noreturn__)) leaveBootloader(void);
static void leaveBootloader(void) {
  asm  volatile  (
  "cli\n\t"
  "sbi		%[usbddr],	%[usbminus]\n\t"  
  "cbi		%[port],	%[bit]\n\t"
  "out		%[usbintrenab],	__zero_reg__\n\t"
  "out		%[usbintrcfg],	__zero_reg__\n\t"
  "ldi		r31,		%[ivce]\n\t"
  "out		%[mygicr],	r31\n\t"
  "out		%[mygicr],	__zero_reg__\n\t"  
  "rjmp		nullVector\n\t"
  :
  : [port]        "I" (_SFR_IO_ADDR(PIN_PORT(JUMPER_PORT))),
    [bit]         "I" (PIN(JUMPER_PORT, JUMPER_BIT)),
    [usbintrenab] "I" (_SFR_IO_ADDR(USB_INTR_ENABLE)),
    [usbintrcfg]  "I" (_SFR_IO_ADDR(USB_INTR_CFG)),
    [usbddr]      "I" (_SFR_IO_ADDR(USBDDR)),
    [usbminus]    "I" (USBMINUS),
    [mygicr]      "I" (_SFR_IO_ADDR(GICR)),	      
    [ivce]        "I" (1<<IVCE)
);
}
#else
static void __attribute__((__noreturn__)) leaveBootloader(void);
static void leaveBootloader(void) {
    DBG1(0x01, 0, 0);
    cli();
    usbDeviceDisconnect();
    bootLoaderExit();
    USB_INTR_ENABLE = 0;
    USB_INTR_CFG = 0;       /* also reset config bits */
    GICR = (1 << IVCE);     /* enable change of interrupt vectors */
    GICR = (0 << IVSEL);    /* move interrupts to application flash section */

/* restore the original watchdog timer if necessary */
#if (__IMPLEMENT_PRESERVE_WATCHDOG)
    if (__original_WDTCR & _BV(WDE)) {
      __original_WDTCR &= ~(_BV(WDCE));
      wdt_reset();
      WDTCR |= (_BV(WDCE)) | (_BV(WDE));
      WDTCR  = __original_WDTCR;
      wdt_reset();
    }
#endif
/*
 * There seems to be another funny compiler Bug.
 * When gcc is using "eicall" opcode it forgets to modify EIND.
 * On devices with large flash memory there are some target address bits
 * missing. In this case some zero bits...
 */
#if (defined(EIND) && ((FLASHEND)>131071))
  EIND=0;
#endif
/* We must go through a global function pointer variable instead of writing
 *  ((void (*)(void))0)();
 * because the compiler optimizes a constant 0 to "rcall 0" which is not
 * handled correctly by the assembler.
 */
    nullVector();
}
#endif

/* ------------------------------------------------------------------------ */


uchar usbFunctionSetup_USBASP_FUNC_TRANSMIT(usbRequest_t *rq) {
  uchar rval = 0;
  usbWord_t address;
  address.bytes[1] = rq->wValue.bytes[1];
  address.bytes[0] = rq->wIndex.bytes[0];

  if(rq->wValue.bytes[0] == 0x30){        /* read signature */
    rval = rq->wIndex.bytes[0] & 3;
    rval = signatureBytes[rval];
#if HAVE_READ_LOCK_FUSE
#if defined (__AVR_ATmega8535__) || 					\
    defined (__AVR_ATmega8__) || defined (__AVR_ATmega8A__) || 		\
    defined (__AVR_ATmega16__) || defined (__AVR_ATmega32__)
  }else if(rq->wValue.bytes[0] == 0x58 && rq->wValue.bytes[1] == 0x00){  /* read lock bits */
      rval = boot_lock_fuse_bits_get(GET_LOCK_BITS);
  }else if(rq->wValue.bytes[0] == 0x50 && rq->wValue.bytes[1] == 0x00){  /* read lfuse bits */
      rval = boot_lock_fuse_bits_get(GET_LOW_FUSE_BITS);
  }else if(rq->wValue.bytes[0] == 0x58 && rq->wValue.bytes[1] == 0x08){  /* read hfuse bits */
      rval = boot_lock_fuse_bits_get(GET_HIGH_FUSE_BITS);

#elif defined (__AVR_ATmega48__)   || defined (__AVR_ATmega48A__)   || defined (__AVR_ATmega48P__)   || defined (__AVR_ATmega48PA__)  ||  \
defined (__AVR_ATmega88__)   || defined (__AVR_ATmega88A__)   || defined (__AVR_ATmega88P__)   || defined (__AVR_ATmega88PA__)  ||  \
defined (__AVR_ATmega162__)  || 												      \
defined (__AVR_ATmega164A__) || defined (__AVR_ATmega164P__)  || 								      \
defined (__AVR_ATmega168__)  || defined (__AVR_ATmega168A__)  || defined (__AVR_ATmega168P__)  || defined (__AVR_ATmega168PA__) ||  \
defined (__AVR_ATmega324A__) || defined (__AVR_ATmega324P__)  ||								      \
defined (__AVR_ATmega328__)  || defined (__AVR_ATmega328P__)  ||								      \
defined (__AVR_ATmega640__)  ||													\
defined (__AVR_ATmega644__)  || defined (__AVR_ATmega644A__)  || defined (__AVR_ATmega644P__) || defined (__AVR_ATmega644PA__)  ||  \
defined (__AVR_ATmega128__)  ||													      \
defined (__AVR_ATmega1280__) ||													\
defined (__AVR_ATmega1281__) ||													\
defined (__AVR_ATmega1284__) || defined (__AVR_ATmega1284P__)  ||													\
defined (__AVR_ATmega2560__) ||													\
defined (__AVR_ATmega2561__)
  }else if(rq->wValue.bytes[0] == 0x58 && rq->wValue.bytes[1] == 0x00){  /* read lock bits */
      rval = boot_lock_fuse_bits_get(GET_LOCK_BITS);
  }else if(rq->wValue.bytes[0] == 0x50 && rq->wValue.bytes[1] == 0x00){  /* read lfuse bits */
      rval = boot_lock_fuse_bits_get(GET_LOW_FUSE_BITS);
  }else if(rq->wValue.bytes[0] == 0x58 && rq->wValue.bytes[1] == 0x08){  /* read hfuse bits */
      rval = boot_lock_fuse_bits_get(GET_HIGH_FUSE_BITS);
  }else if(rq->wValue.bytes[0] == 0x50 && rq->wValue.bytes[1] == 0x08){  /* read efuse bits */
      rval = boot_lock_fuse_bits_get(GET_EXTENDED_FUSE_BITS );
#else
  #warning "HAVE_READ_LOCK_FUSE is activated but MCU unknown -> will not support this feature"
#endif
#endif
#if HAVE_FLASH_BYTE_READACCESS
  }else if(rq->wValue.bytes[0] == 0x20){  /* read FLASH low  byte */
#if ((FLASHEND) > 65535)
      rval = pgm_read_byte_far((((addr_t)address.word)<<1)+0);
#else
      rval = pgm_read_byte((((addr_t)address.word)<<1)+0);
#endif
  }else if(rq->wValue.bytes[0] == 0x28){  /* read FLASH high byte */
#if ((FLASHEND) > 65535)
      rval = pgm_read_byte_far((((addr_t)address.word)<<1)+1);
#else
      rval = pgm_read_byte((((addr_t)address.word)<<1)+1);
#endif
#endif
#if HAVE_EEPROM_BYTE_ACCESS
  }else if(rq->wValue.bytes[0] == 0xa0){  /* read EEPROM byte */
      rval = eeprom_read_byte((void *)address.word);
  }else if(rq->wValue.bytes[0] == 0xc0){  /* write EEPROM byte */
      eeprom_write_byte((void *)address.word, rq->wIndex.bytes[1]);
#endif
#if HAVE_CHIP_ERASE
  }else if(rq->wValue.bytes[0] == 0xac && rq->wValue.bytes[1] == 0x80){  /* chip erase */
      addr_t addr;
#if HAVE_BLB11_SOFTW_LOCKBIT
      for(addr = 0; addr < (addr_t)(BOOTLOADER_PAGEADDR) ; addr += SPM_PAGESIZE) {
#else
      for(addr = 0; addr <= (addr_t)(FLASHEND) ; addr += SPM_PAGESIZE) {
#endif
	  /* wait and erase page */
	  DBG1(0x33, 0, 0);
#   ifndef NO_FLASH_WRITE
	  boot_spm_busy_wait();
	  cli();
	  boot_page_erase(addr);
	  sei();
#   endif
      }
#endif
#if ((HAVE_BOOTLOADER_HIDDENEXITCOMMAND) && (BOOTLOADER_CAN_EXIT))
#	if ((HAVE_BOOTLOADER_HIDDENEXITCOMMAND != 0xac) && \
	    (HAVE_BOOTLOADER_HIDDENEXITCOMMAND != 0x20) && (HAVE_BOOTLOADER_HIDDENEXITCOMMAND != 0x28) && \
	    (HAVE_BOOTLOADER_HIDDENEXITCOMMAND != 0x40) && (HAVE_BOOTLOADER_HIDDENEXITCOMMAND != 0x48) && \
	    (HAVE_BOOTLOADER_HIDDENEXITCOMMAND != 0x4c) && \
	    (HAVE_BOOTLOADER_HIDDENEXITCOMMAND != 0xa0) && \
	    (HAVE_BOOTLOADER_HIDDENEXITCOMMAND != 0xc0) && \
	    (HAVE_BOOTLOADER_HIDDENEXITCOMMAND != 0x58) && \
	    (HAVE_BOOTLOADER_HIDDENEXITCOMMAND != 0x5c) && \
	    (HAVE_BOOTLOADER_HIDDENEXITCOMMAND != 0x30) && \
	    (HAVE_BOOTLOADER_HIDDENEXITCOMMAND != 0xac) && \
	    (HAVE_BOOTLOADER_HIDDENEXITCOMMAND != 0x50) && (HAVE_BOOTLOADER_HIDDENEXITCOMMAND != 0x58) && \
	    (HAVE_BOOTLOADER_HIDDENEXITCOMMAND != 0x38))
  }else if(rq->wValue.bytes[0] == (HAVE_BOOTLOADER_HIDDENEXITCOMMAND)){  /* cause a bootLoaderExit at disconnect */
      stayinloader = 0xf1;  /* we need to be connected - so assume it */
#	endif
#endif
  }else{
      /* ignore all others, return default value == 0 */
  }
        
  return rval;
}


usbMsgLen_t usbFunctionSetup(uchar data[8])
{
usbRequest_t    *rq = (void *)data;
usbMsgLen_t     len = 0;
static uchar    replyBuffer[4];

    usbMsgPtr = (usbMsgPtr_t)replyBuffer;
    if(rq->bRequest == USBASP_FUNC_TRANSMIT){   /* emulate parts of ISP protocol */
        replyBuffer[3] = usbFunctionSetup_USBASP_FUNC_TRANSMIT(rq);
        len = (usbMsgLen_t)4;
    }else if((rq->bRequest == USBASP_FUNC_ENABLEPROG) || (rq->bRequest == USBASP_FUNC_SETISPSCK)){
        /* replyBuffer[0] = 0; is never touched and thus always 0 which means success */
        len = (usbMsgLen_t)1;
    }else if(rq->bRequest >= USBASP_FUNC_READFLASH && rq->bRequest <= USBASP_FUNC_SETLONGADDRESS){
        currentAddress.w[0] = rq->wValue.word;
        if(rq->bRequest == USBASP_FUNC_SETLONGADDRESS){
#if (FLASHEND) > 0xffff
            currentAddress.w[1] = rq->wIndex.word;
#endif
        }else{
            bytesRemaining = rq->wLength.bytes[0];
            /* if(rq->bRequest == USBASP_FUNC_WRITEFLASH) only evaluated during writeFlash anyway */
            isLastPage = rq->wIndex.bytes[1] & 0x02;
#if HAVE_EEPROM_PAGED_ACCESS
            currentRequest = rq->bRequest;
#endif
            len = USB_NO_MSG; /* hand over to usbFunctionRead() / usbFunctionWrite() */
        }

    }else if(rq->bRequest == USBASP_FUNC_DISCONNECT){

#if BOOTLOADER_CAN_EXIT
#	ifdef CONFIG_HAVE__BOOTLOADER_ABORTTIMEOUTONACT
      /* let the main loop know for ever that here was activity */
      stayinloader	   &= (0xfc);
#	else
      stayinloader	   &= (0xfe);
#	endif
#endif
    }else{
        /* ignore: others, but could be USBASP_FUNC_CONNECT */
#if BOOTLOADER_CAN_EXIT
	stayinloader	   |= (0x01);
#endif
    }
    return len;
}

#if (USE_EXCESSIVE_ASSEMBLER) && ((!HAVE_CHIP_ERASE) || (HAVE_ONDEMAND_PAGEERASE)) && (SPM_PAGESIZE <= 256) && (((BOOTLOADER_PAGEADDR>>0)&0xff) == 0)
uchar usbFunctionWrite(uchar *data, uchar len)
{
uchar   isLast;

    DBG1(0x31, (void *)&currentAddress.l, 4);
    if(len > bytesRemaining)
        len = bytesRemaining;
    bytesRemaining -= len;
    isLast = bytesRemaining == 0;
    if(currentRequest >= USBASP_FUNC_READEEPROM){
        uchar i;
        for(i = 0; i < len; i++){
            eeprom_write_byte((void *)(currentAddress.w[0]++), *data++);
        }
    }else{
	asm  volatile  (
	  "sbrc		%[len], 0\n\t"
	  "inc		%[len]\n\t"
"usbFunctionWrite_flashloop:\n\t"
	  "subi		%[len], 2\n\t"
	  "brlo		usbFunctionWrite_finished\n\t"
	  
#if HAVE_BLB11_SOFTW_LOCKBIT
	  "cpi		r31, %[blsaddrhi]\n\t"			/* accelerated BLB11_SOFTW_LOCKBIT check */
	  "brsh		usbFunctionWrite_finished\n\t"
// 	  "brlo		usbFunctionWrite_addrunlock_ok\n\t"
// 	  "brne		usbFunctionWrite_finished\n\t"
// 	  "cpi		r30, %[blsaddrlo]\n\t"
// 	  "brlo		usbFunctionWrite_addrunlock_ok\n\t"
// 	  "rjmp		usbFunctionWrite_finished\n\t"
// "usbFunctionWrite_addrunlock_ok:\n\t"
#endif
	  "rcall	usbFunctionWrite_waitA\n\t"
	  "cli\n\t"						/* r0 or r1 may be __zero_reg__ and may become dangerous nonzero within interrupts */
	  "ld		r0,		X+\n\t"
	  "ld		r1,		X+\n\t"

	  "ldi		r18,		%[pagfillval]\n\t"
	  "rcall	usbFunctionWrite_saveflash\n\t"	/* page fill */

	  "mov		r18,		r30\n\t"
	  "subi		r18,		0xfe\n\t"		/* add with 2 */
	  "andi		r18,		%[pagemask]\n\t"
	  "breq		usbFunctionWrite_pageisfull\n\t"
	  "tst		%[islast]\n\t"
	  "breq		usbFunctionWrite_skippageisfull\n\t"
	  "tst		%[isLastPage]\n\t"
	  "breq		usbFunctionWrite_skippageisfull\n\t"
	  "cpi		%[len],		0\n\t"
	  "brne		usbFunctionWrite_skippageisfull\n\t"

"usbFunctionWrite_pageisfull:\n\t"				/* start writing the page */
	  "ldi		r18,		%[pageraseval]\n\t"
	  "rcall	usbFunctionWrite_saveflash\n\t"	/* page erase */
	  "rcall	usbFunctionWrite_waitA\n\t"

	  "ldi		r18,		%[pagwriteval]\n\t"
	  "rcall	usbFunctionWrite_saveflash\n\t"	/* page write */
	  "rcall	usbFunctionWrite_waitA\n\t"

	  "in		__tmp_reg__,	%[spmcr]\n\t"
	  "sbrs		__tmp_reg__,	%[rwwsbbit]\n\t"
	  "rjmp		usbFunctionWrite_skippageisfull\n\t"
	  "ldi		r18,		%[rwwenrval]\n\t"
	  "rcall	usbFunctionWrite_saveflash\n\t"	/* reenable rww*/
// 	  "rcall	usbFunctionWrite_waitA\n\t"


"usbFunctionWrite_skippageisfull:\n\t"	  
	  "adiw		r30,		0x2\n\t"
	  "rjmp		usbFunctionWrite_flashloop\n\t"

"usbFunctionWrite_saveflash:\n\t"
	  "cli\n\t"
	  "out		%[spmcr],	r18\n\t"
	  "spm\n\t"
	  "clr		__zero_reg__\n\t"			/* if r0 or r1 is __zero_reg__ it may have become inconsisten while page-fill */
	  "sei\n\t"
	  "ret\n\t"

"usbFunctionWrite_waitA:\n\t"
	  "in		__tmp_reg__,	%[spmcr]\n\t"
	  "sbrc		__tmp_reg__,	%[spmenbit]\n\t"
	  "rjmp		usbFunctionWrite_waitA\n\t"
	  "ret\n\t"
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

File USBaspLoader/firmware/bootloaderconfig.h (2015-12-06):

/* Name: bootloaderconfig.h
 * Project: USBaspLoader
 * Author: Christian Starkjohann
 * Author: Stephan Baerwolf
 * Creation Date: 2007-12-08
 * Modification Date: 2013-03-31
 * Tabsize: 4
 * Copyright: (c) 2007 by OBJECTIVE DEVELOPMENT Software GmbH
 * License: GNU GPL v2 (see License.txt)
 */

#ifndef __bootloaderconfig_h_included__
#define __bootloaderconfig_h_included__
#include "../misc/iofixes.h"

/*
General Description:
This file (together with some settings in Makefile) configures the boot loader
according to the hardware.

This file contains (besides the hardware configuration normally found in
usbconfig.h) two functions or macros: bootLoaderInit() and
bootLoaderCondition(). Whether you implement them as macros or as static
inline functions is up to you, decide based on code size and convenience.

bootLoaderInit() is called as one of the first actions after reset. It should
be a minimum initialization of the hardware so that the boot loader condition
can be read. This will usually consist of activating a pull-up resistor for an
external jumper which selects boot loader mode.

bootLoaderCondition() is called immediately after initialization and in each
main loop iteration. If it returns TRUE, the boot loader will be active. If it
returns FALSE, the boot loader jumps to address 0 (the loaded application)
immediately.

For compatibility with Thomas Fischl's avrusbboot, we also support the macro
names BOOTLOADER_INIT and BOOTLOADER_CONDITION for this functionality. If
these macros are defined, the boot loader usees them.
*/

/* ---------------------------- Macro Magic ---------------------------- */
#define		PIN_CONCAT(a,b)			a ## b
#define		PIN_CONCAT3(a,b,c)		a ## b ## c

#define		PIN_PORT(a)			PIN_CONCAT(PORT, a)
#define		PIN_PIN(a)			PIN_CONCAT(PIN, a)
#define		PIN_DDR(a)			PIN_CONCAT(DDR, a)

#define		PIN(a, b)			PIN_CONCAT3(P, a, b)

/* ---------------------------- Hardware Config ---------------------------- */

#ifndef USB_CFG_IOPORTNAME
  #define USB_CFG_IOPORTNAME      D
#endif
/* This is the port where the USB bus is connected. When you configure it to
 * "B", the registers PORTB, PINB and DDRB will be used.
 */
#ifndef USB_CFG_INTPORT_BIT
  #if (defined(__AVR_ATmega640__) || defined (__AVR_ATmega128__) || defined(__AVR_ATmega1280__) || defined(__AVR_ATmega1281__) || defined(__AVR_ATmega2560__) || defined(__AVR_ATmega2561__))
    #define USB_CFG_INTPORT_BIT 0
  #else
    #define USB_CFG_INTPORT_BIT 2
  #endif
#endif
/* Not all devices have their INT0 on PD2.
 * Since "INT0" and "USB_CFG_DPLUS_BIT" should get the same signals,
 * map them to be ideally the same:
 * So abstract "USB_CFG_DPLUS_BIT" to this one here.
 */

#ifndef USB_CFG_DMINUS_BIT
  /* This is Revision 3 and later (where PD6 and PD7 were swapped */
  #define USB_CFG_DMINUS_BIT      7    /* Rev.2 and previous was 6 */
#endif
/* This is the bit number in USB_CFG_IOPORT where the USB D- line is connected.
 * This may be any bit in the port.
 */
#ifndef USB_CFG_DPLUS_BIT
  #define USB_CFG_DPLUS_BIT       USB_CFG_INTPORT_BIT
#endif
/* This is the bit number in USB_CFG_IOPORT where the USB D+ line is connected.
 * This may be any bit in the port. Please note that D+ must also be connected
 * to interrupt pin INT0!
 */
#ifndef JUMPER_PORT
  #define JUMPER_PORT		C	/* was USB_CFG_INTPORT_BIT in matrixstorm.com version*/
#endif
/* 
 * jumper is connected to this port
 */
#ifndef JUMPER_BIT
  /* Swaped JUMPER from PD6 to PC3 */
  #define JUMPER_BIT           3       /* rev3-smd was 3 */
#endif
/* 
 * jumper is connected to this bit in port "JUMPER_PORT", active low
 */

#define USB_CFG_CLOCK_KHZ       (F_CPU/1000)
/* Clock rate of the AVR in MHz. Legal values are 12000, 16000 or 16500.
 * The 16.5 MHz version of the code requires no crystal, it tolerates +/- 1%
 * deviation from the nominal frequency. All other rates require a precision
 * of 2000 ppm and thus a crystal!
 * Default if not specified: 12 MHz
 */

/* ----------------------- Optional Hardware Config ------------------------ */

/* #define USB_CFG_PULLUP_IOPORTNAME   D */
/* If you connect the 1.5k pullup resistor from D- to a port pin instead of
 * V+, you can connect and disconnect the device from firmware by calling
 * the macros usbDeviceConnect() and usbDeviceDisconnect() (see usbdrv.h).
 * This constant defines the port on which the pullup resistor is connected.
 */
/* #define USB_CFG_PULLUP_BIT          4 */
/* This constant defines the bit number in USB_CFG_PULLUP_IOPORT (defined
 * above) where the 1.5k pullup resistor is connected. See description
 * above for details.
 */

/* ------------------------------------------------------------------------- */
/* ---------------------- feature / code size options ---------------------- */
/* ------------------------------------------------------------------------- */
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

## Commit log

2015-12-03 added exercise schematic
    [tinyusbboard-exercise.sch, tinyusbboard.brd, tinyusbboard.sch]
2015-12-07 added Arduino Archive
2015-12-07 added json for copy paste board install
2015-12-08 added instructions for use with Arduino IDE
2015-12-15 Updatet Anleitung nach Erfahrungen des ersten Tutorials
2015-12-20 switch demo added

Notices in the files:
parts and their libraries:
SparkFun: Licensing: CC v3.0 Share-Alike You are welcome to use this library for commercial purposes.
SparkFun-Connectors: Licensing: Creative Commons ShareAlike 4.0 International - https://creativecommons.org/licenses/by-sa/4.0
